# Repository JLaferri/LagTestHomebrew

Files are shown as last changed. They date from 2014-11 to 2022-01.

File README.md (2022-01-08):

Right now this readme will contain the very minimal information required to duplicate my lag tester. If anyone wants to make a more detailed guide I'm open to placing it here, or linking to it.

Here is a demonstation video of the device in use: https://www.youtube.com/watch?v=UTNUIQtreXQ

## Theory and Limitations
Currently this method only works using a Wii with homebrew channel installed. In order for the test to work you need to have a display that emits white light synced up with a sound cue. Both are picked up by the board and the offset is used to calculate the lag. The theory behind it is that the audio will never be delayed whereas the video will be. A CRT is used for calibration.

The Wii limitation could be eliminated if someone designed something else that created these same signals on generic displays. The nice thing about using the Wii is that you know you are providing the same output to the monitor that you would playing a smash game on Wii.

## Board
Click the following link to order some boards or download the gerbers:



Another fab that I recommend if you want to get a few more made is https://www.seeedstudio.com/fusion_pcb.html

## Components
https://docs.google.com/spreadsheets/d/1Dj-m-Ip__IdE_k23mZq7f_099_O0pOspUQSO7Uzj5Qs/edit?usp=sharing

The above were the parts I used at some point... This was actually a long time ago so I'm not even sure how useful those part numbers are going to be but it's the best I have.

### Soldering Guide
This isn't really a guide so much as an aid to tell you where to place what components...
https://github.com/JLaferri/LagTestHomebrew/blob/master/SolderGuide.pdf

### Flashing the Processor
Once you have soldered the board together you will need to flash the processor with the code required to do the testing and run the display. The processor design is based on an Arduino and this can be done using the Arduino IDE. Open the IDE, select the correct programmer, and flash using the programmer. You will need a programmer such as https://www.sparkfun.com/products/9825

The Arduino file can be found here:
https://github.com/JLaferri/LagTestHomebrew/blob/master/Arduino%20Code/lagtester_current.ino

## Homebrew App
The following folder contains the app files to be used on homebrew channel on a hacked Wii
https://github.com/JLaferri/LagTestHomebrew/tree/master/HomebrewApp/compiled/LagTestHomebrew

### Building
For instructions on making changes to the app and building, go here: https://github.com/JLaferri/LagTestHomebrew/tree/master/HomebrewApp

## Additional Materials
Depending on what you intend to test you might need audio converters/extenders. Here are a few that I've used:
* https://www.amazon.com/gp/product/B00004Z5CP
* https://www.amazon.com/Female-Audio-Extension-Cable-CNE63133/dp/B00B973X20

You'll also need to purchase a 9V battery.

## Instructions
This sections explains how to actually use the tester

### Calibration
To add... I think it works kinda like the process in the next section but you gotta hold the button down first? I need to remember how to do this lol. Without calibrating, however, results will be meaningless. A "safe" CRT should be used to calibrate.

### Executing a Test
1. Ensure that the room you are testing in is not flooded with sunlight. The light sensor works by detecting lux and the sun will saturate the voltage output because it produces a lot of it. Too much artificial lighting is also not good but you should be fine as long as there's not a really bright light right behind the monitor you're testing or something.
2. Place a 9V battery in holder. The polarity is marked on the plastic. Do not reverse the polarity as I have not tested what would happen if you do. Worst case scenario, you'd fry the board. More likely though is that nothing would happen.
3. Plug audio cable into the device. Ideally this audio source comes directly from the Wii. In the case of the Sewell adapter use the cable I provided at its output and plug into board. If using component cables you might need to get an RCA connection extender for the audio to reach the device while maintaining mobility. You can also use the audio output of the monitor if it has one but you run the risk that if the monitor adds latency to the audio signal the measurement will be wrong.
4. Turn on the device by flipping the on off switch to on.
5. Boot into the homebrew app.
6. A white bar should be flashing on and off on the monitor, this is the test area. Place the device such that the clear light sensor on the bottom of the board is over the test area. For a CRT, keep a fair distance from the screen (probably at least 5 inches), you don't need to be overly precise about being directly in front of the test area on a CRT as it shoots out a fair amount of light. For an LCD I would recommend placing the sensor about half an inch to one inch away from the screen.
7. Holding the tester in place in front of the test area, press the push button on the top of the board. Wait until either an error code, indicated by the value Err#, or a result in milliseconds appears on the display.
8. Optionally take a few measurements to ensure repeatability.
9. Press A on the Wii Mote to move to the next test area.
10. Repeat steps 6 to 9 for the two other test areas (middle, bottom). Taking an equal amount of measurements for each.
11. Average all results to get the average frame lag of the display. On a CRT this should be close to 8.33 ms.

### Error codes
* Err0 - Audio is not begin detected. Either the amplitude of the audio signal has been reduced (via turning down the volume of a monitor output for example), the homebrew application is not running, or the cable is not plugged in.
* Err1 - Audio cable was disconnected during test?
* Err2 - Audio signal is stuck high for some reason. Not sure what would cause this.
* Err3 - Video signal difference between black and white is not large enough. Is the sensor in front of the test area?

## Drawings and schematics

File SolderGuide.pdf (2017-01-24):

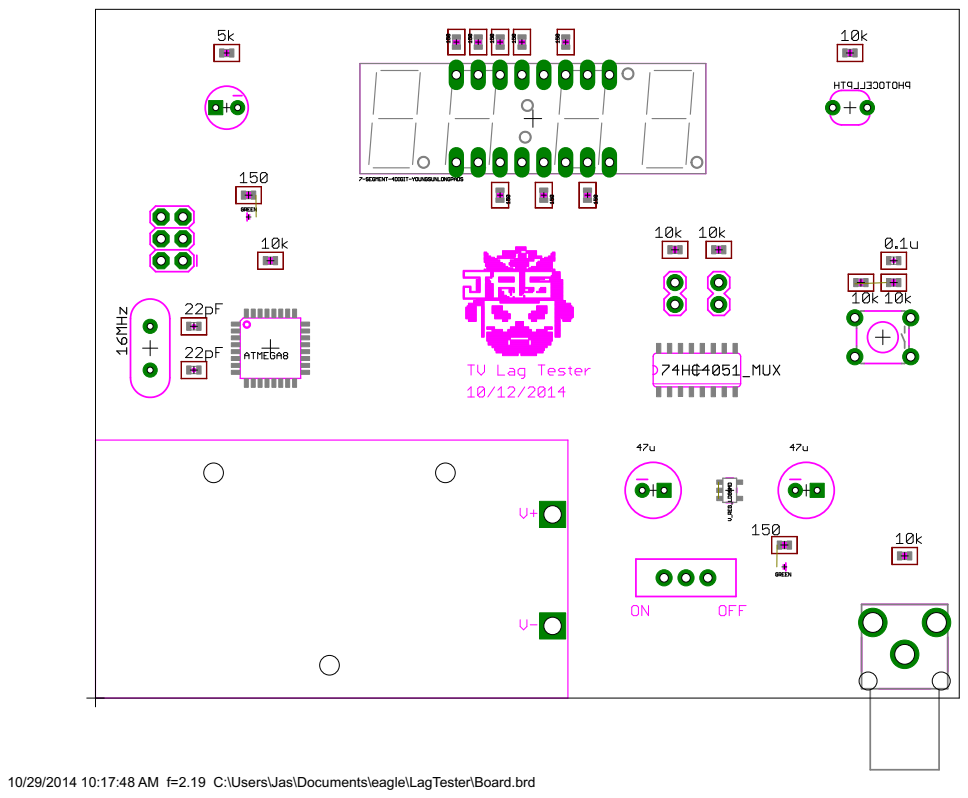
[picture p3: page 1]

10/29/2014 10:17:48 AM f=2.19 C:\Users\Jas\Documents\eagle\LagTester\Board.brd

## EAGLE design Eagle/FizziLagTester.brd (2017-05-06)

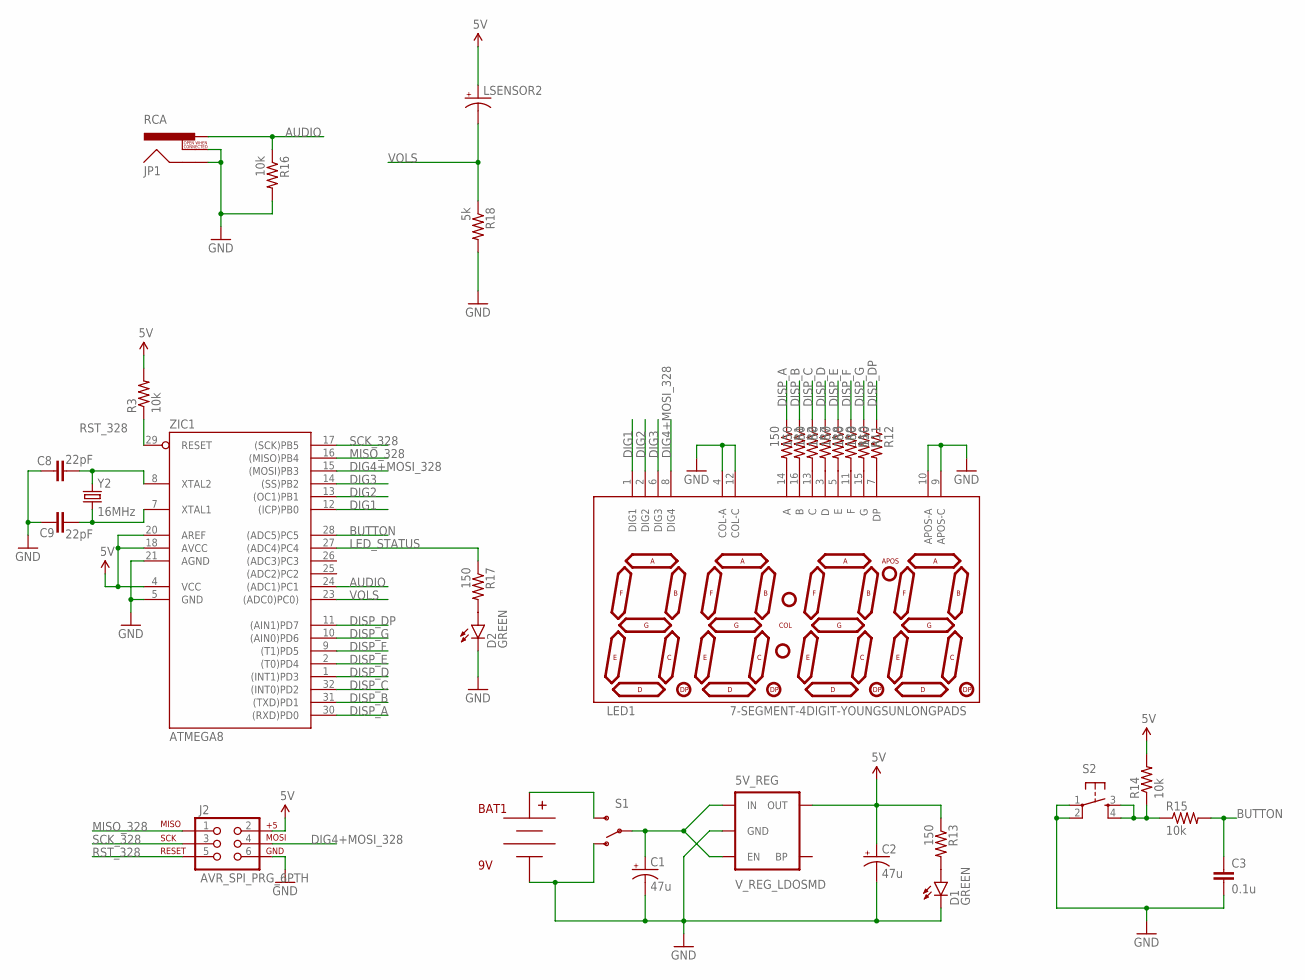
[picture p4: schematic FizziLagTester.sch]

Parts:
5V_REG: V_REG_LDOSMD; SOT23-5
BAT1: 9V; BC9VPC
C1, C2: 47u; CPOL-RADIAL-100UF-25V
C3: 0.1u; 0603-CAP
C8, C9: 22pF; 0603-CAP
D1, D2: GREEN; LED-0603
J2: AVR_SPI_PRG_6PTH; 2X3
JP1: RCA
LED1: 7-SEGMENT-4DIGIT-YOUNGSUNLONGPADS; 7-SEGMENT-4DIGIT-YOUNGSUN-LONGPADS
LSENSOR2: CAP_POLPTH2; CPOL-RADIAL-10UF-25V
R1, R2, R7, R8, R9, R10, R11, R12, R13, R17: 150; 0603-RES
R3, R14, R15, R16: 10k; 0603-RES
R18: 5k; 0603-RES
S1: SWITCH-SPDTPTH; SWITCH-SPDT
S2: TAC_SWITCHPTH; TACTILE-PTH
Y2: 16MHz; HC49US
ZIC1: ATMEGA8; TQFP32-08

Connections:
5V: 5V_REG.5 (OUT), C2.1 (+), J2.2, LSENSOR2.1 (+), R3.2, R13.1, R14.2, ZIC1.4 (VCC), ZIC1.18 (AVCC), ZIC1.20 (AREF)
AUDIO: JP1.PIN, R16.1, ZIC1.24 ((ADC1)PC1)
BUTTON: C3.1, R15.2, ZIC1.28 ((ADC5)PC5)
DIG1: LED1.1 (DIG1), ZIC1.12 ((ICP)PB0)
DIG2: LED1.2 (DIG2), ZIC1.13 ((OC1)PB1)
DIG3: LED1.6 (DIG3), ZIC1.14 ((SS)PB2)
DIG4+MOSI_328: J2.4, LED1.8 (DIG4), ZIC1.15 ((MOSI)PB3)
DISP_A: R1.1, ZIC1.30 ((RXD)PD0)
DISP_B: R2.1, ZIC1.31 ((TXD)PD1)
DISP_C: R7.1, ZIC1.32 ((INT0)PD2)
DISP_D: R8.1, ZIC1.1 ((INT1)PD3)
DISP_DP: R12.1, ZIC1.11 ((AIN1)PD7)
DISP_E: R9.1, ZIC1.2 ((T0)PD4)
DISP_F: R10.1, ZIC1.9 ((T1)PD5)
DISP_G: R11.1, ZIC1.10 ((AIN0)PD6)
GND: 5V_REG.2 (GND), BAT1.V-, C1.2 (-), C2.2 (-), C3.2, C8.2, C9.2, D1.C, D2.C, J2.6, JP1.SHELL, JP1.SWITCH, LED1.4 (COL-A), LED1.9 (APOS-C), LED1.10 (APOS-A), LED1.12 (COL-C), R16.2, R18.2, S1.1 (O), S2.1, S2.2, ZIC1.5 (GND), ZIC1.21 (AGND)
LED_STATUS: R17.1, ZIC1.27 ((ADC4)PC4)
MISO_328: J2.1, ZIC1.16 ((MISO)PB4)
unnamed: LED1.14 (A), R1.2
unnamed: LED1.16 (B), R2.2
unnamed: C8.1, Y2.2, ZIC1.8 (XTAL2)
unnamed: C9.1, Y2.1, ZIC1.7 (XTAL1)
unnamed: LED1.13 (C), R7.2
unnamed: LED1.3 (D), R8.2
unnamed: LED1.5 (E), R9.2
unnamed: LED1.11 (F), R10.2
unnamed: LED1.15 (G), R11.2
unnamed: LED1.7 (DP), R12.2
unnamed: BAT1.V+, S1.3 (S)
unnamed: 5V_REG.1 (IN), 5V_REG.3 (EN), C1.1 (+), S1.2
unnamed: D1.A, R13.2
unnamed: R14.1, R15.1, S2.3, S2.4
unnamed: D2.A, R17.2
RST_328: J2.5, R3.1, ZIC1.29 (RESET)
SCK_328: J2.3, ZIC1.17 ((SCK)PB5)
VOLS: LSENSOR2.2 (-), R18.1, ZIC1.23 ((ADC0)PC0))

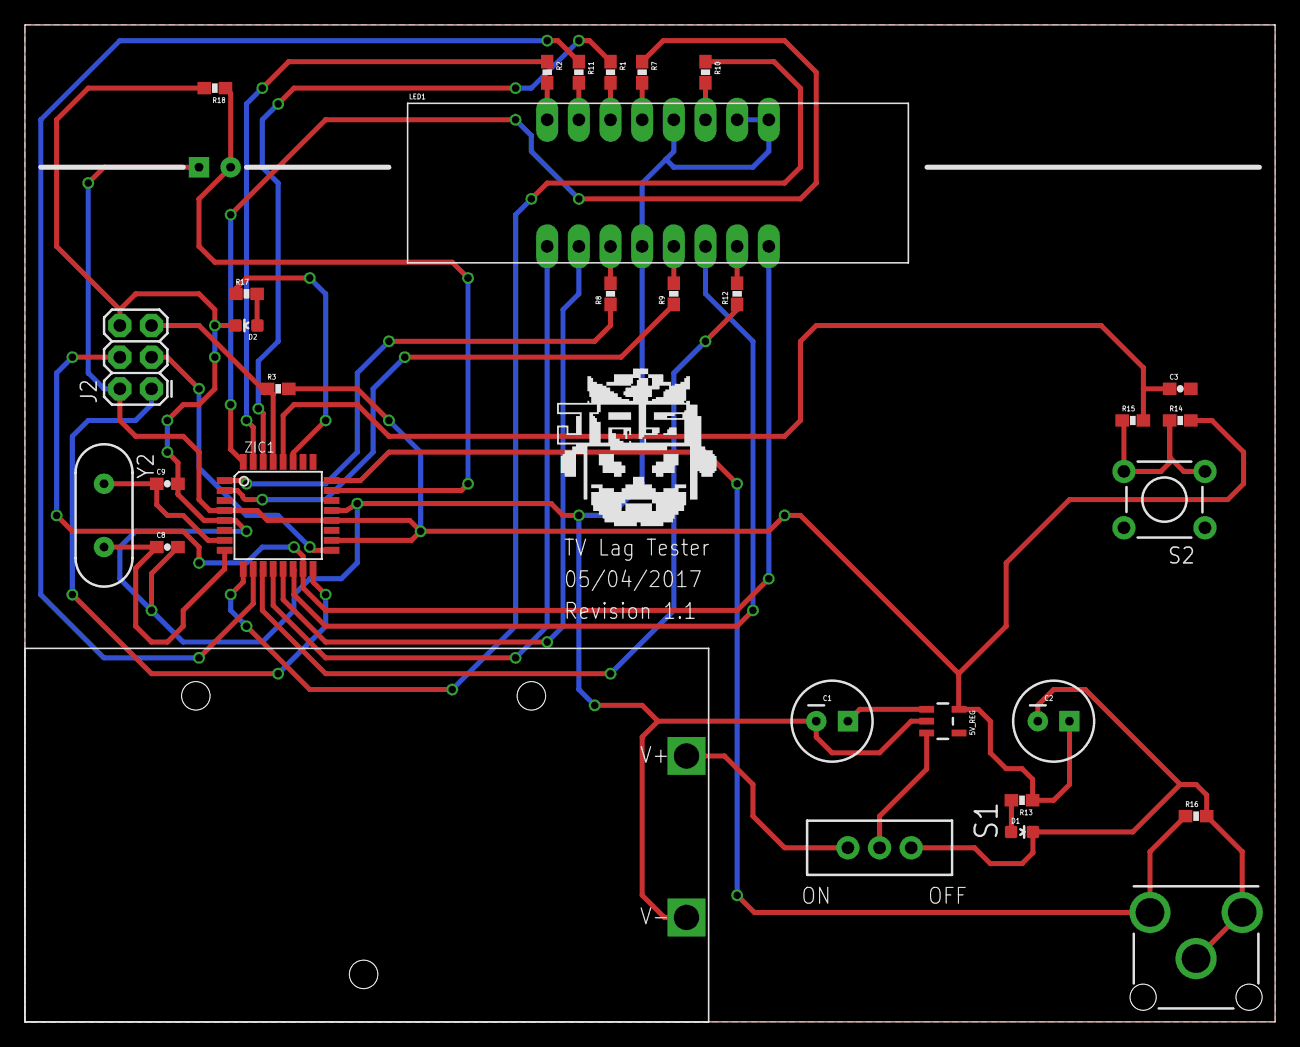
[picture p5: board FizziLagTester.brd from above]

Board: 2 copper layers, 100.3 x 80.0 mm, 32 parts (1 on the bottom side), 36 nets.

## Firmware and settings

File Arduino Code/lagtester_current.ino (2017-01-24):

#include <EEPROM.h>

//Configurable Properties
int ledPin = 18;
int buttonPin = 19;
int lightPin = 0;
int audioPin = 1;

int measurementCountToAverage = 3; //Amount of measurements to average before reporting result

int audioThreshold = 61; //Amount of DAC counts required to detect a positive audio signal
int audioLowThreshold = 5; //DAC count values below this number are considered as no audio signal detected
int lightCountsDifferenceThreshold = 25; //Amount of DAC counts between min and max light values to allow measurement to proceed
float lightRiseRatioRequired = 0.25; //Percent towards maximum light value before the light signal is accepted 
unsigned long measurementSignalOffset_us = 24440; //Average raw frame lag of a CRT. This is basically the amount of desync time between the audio signal and the light signal on the homebrew app
unsigned long calibrationMonitorCenterTime_us = 8333; //The desired measurement reading for the center screen measurement of the calibration monitor (CRT)

unsigned long periodMicros = 1000000; //The period of the audio and light signal in microseconds
int periodCountInitialization = 3; //Amount of periods to wait to get a good concept of the min and max light values

//Sequencing Properties
unsigned long period150Percent = periodMicros + (periodMicros / 2);
unsigned long period200Percent = 2 * periodMicros;
unsigned long period25Percent = periodMicros / 4;
unsigned long periodMicrosLess10Percent = periodMicros - (periodMicros / 10);
unsigned long periodMicrosPlus10Percent = periodMicros + (periodMicros / 10);
unsigned long timeoutMicros = (periodMicros / 2) - (periodMicros / 20);

byte digits[] =
{
  B11111111,
  B11111111,
  B11111111,
  B11111111
};

int currentDigit = 0;

boolean isMeasuring = false;
boolean isCalibration = false;
boolean isButtonPressed = false;
boolean audioDetected = false;

unsigned long measurementStartTime = 0;
unsigned long audioTime = 0;

unsigned long buttonPressTime = 0;

unsigned long buttonTimeForCal_ms = 5000;

int lightMax = 0;
int lightMin = 1023;
int lightThreshold = 0;

int measurementCount = 0;
long measurementAverage = 0;

void setup()
{
  //Set all of PortD pins as outputs
  DDRD = B11111111;
  
  //Set the first 4 bits of PortB as outputs
  DDRB = DDRB | B00001111;
  
  //Initialize Status LED pin
  pinMode(ledPin, OUTPUT);
  digitalWrite(ledPin, LOW);
  
  //Initialize button pin
  pinMode(buttonPin, INPUT);
  
  //Load calibration value
  loadCalValue();
  
  //Initialize digits
  setDigits("0.000");
}

void loadCalValue()
{
  unsigned long value = (EEPROM.read(0) << 24) | EEPROM.read(1) << 16 | EEPROM.read(2) << 8 | EEPROM.read(3);
  
  //If calibration value is not set, set it to the default
  if (value == 0xFFFF)
  {
    setCalValue(measurementSignalOffset_us);
  }
  else
  {
    measurementSignalOffset_us = value; 
  }
}

void setCalValue(unsigned long value)
{
  EEPROM.write(0, byte(value >> 24));
  EEPROM.write(1, byte(value >> 16));
  EEPROM.write(2, byte(value >> 8));
  EEPROM.write(3, byte(value));
  
  measurementSignalOffset_us = value;
}

void turnOnStatusLed()
{
  digitalWrite(ledPin, HIGH);
}

void turnOffStatusLed()
{
  digitalWrite(ledPin, LOW);
}

byte getBitsFromChar(char c)
{
  switch(c)
  {
    case '0':
      return B11000000;
    case '1':
      return B11111001;
    case '2':
      return B10100100;
    case '3':
      return B10110000;
    case '4':
      return B10011001;
    case '5':
      return B10010010;
    case '6':
      return B10000010;
    case '7':
      return B11111000;
    case '8':
      return B10000000;
    case '9':
      return B10010000;
    case 'H':
      return B10001001;
    case 'h':
      return B10001011;
    case 'E':
      return B10000110;
    case 'r':
      return B10101111;
    case 'C':
      return B11000110;
    case 'A':
      return B10001000;
    case 'L':
      return B11000111;
    case '-':
      return B10111111;
    case '.':
      return B01111111;
    default:
      return B11111111;
  }
}

void setDigits(String str)
{
  int charCount = str.length();
  int count = 0, digCount = 0;
  
  while(count < charCount && digCount < 4)
  {
    char currentCharacter = str[count];
    byte bits = getBitsFromChar(currentCharacter);
    
    if (currentCharacter != '.' && (count + 1) < charCount && str[count + 1] == '.')
    {
      digits[digCount] = bits & B01111111;
      count++;
    }
    else
    {
      digits[digCount] = bits;
    }
    
    digCount++;
    count++; 
  }
}

void setDigits(float value)
{
  char buf[12]; // needs to be at least large enough to fit the formatted text
  dtostrf(value, 4, 4, buf);
  
  setDigits(String(buf));
}

void displayAlternatingDigit()
{
  //Enable current digit
  PORTB = (PORTB & B11110000) | (B0001 << currentDigit);
  
  //Turn on bits for current digit value
  PORTD = digits[currentDigit];
  
  currentDigit = (currentDigit + 1) % 4;
}

void displaySingleDigit(char digit, byte locations)
{
  //Enable digits specified by locations byte
  PORTB = (PORTB & B11110000) | (locations & B1111);
  
  //Set digit to passed digit
  PORTD = getBitsFromChar(digit);
}

void initializeMeasurement()
{
  isMeasuring = true;
  measurementStartTime = micros();
  
  audioTime = 0;
  audioDetected = false;
  
  measurementCount = 0;
  measurementAverage = 0;
  
  lightMax = 0;
  lightMin = 1023;

  //Measurement is starting, synchronize procedure by waiting for one entire period while polling the light sensor.
  //This will also keep track of the min and max light values for calculating percent of max brightness (75% default).
  //This is so that CRTs and LCDs have a more fair comparison because LCDs take time to reach full brightness.
  unsigned long timeToAccumulateLight = periodMicros * periodCountInitialization;
  while (getTimeSpanValue(measurementStartTime, micros()) < timeToAccumulateLight)
  {
    int lightCounts = analogRead(lightPin);
  
    if (lightCounts > lightMax) lightMax = lightCounts;
    if (lightCounts < lightMin) lightMin = lightCounts;
  }
  
  lightThreshold = (int)floor(lightMin + lightRiseRatioRequired * (lightMax - lightMin));
  
  //Wait until signal is low
  unsigned long audioTimeoutTime = timeToAccumulateLight + periodMicros;
  while (analogRead(audioPin) > audioLowThreshold)
  {
    //If time since measurement start is greater than 1 second, throw an error.
    if (getTimeSpanValue(measurementStartTime, micros()) > audioTimeoutTime)
    {
      setDigits("Err2");
      isMeasuring = false; //Return to displaying digits
    }
  }
  
  //If min and max light values are not different enough, throw error. This would mean light is saturated or no light is being detected
  if (isMeasuring && lightMax - lightMin < lightCountsDifferenceThreshold)
  {
    setDigits("Err3");
    isMeasuring = false; //Return to displaying digits
  }
}

unsigned long getTimeSpanValue(unsigned long past, unsigned long current)
{
    //Add overflow logic to this function
    return current - past;
}

void loop()
{
  if (!isMeasuring)
  {
    //Until measurement starts display different digits
    displayAlternatingDigit();
    delay(2);
      
    byte buttonResult = digitalRead(buttonPin);
    
    if (buttonResult == LOW && !isButtonPressed)
    {
      //Button press falling edge
      buttonPressTime = millis();
      isButtonPressed = true;
      
      //Turn off cal LED when button is pressed
      turnOffStatusLed();
      isCalibration = false;
    }
    else if (buttonResult == HIGH && isButtonPressed)
    {
       //Button was released, start measurement
       
       //Set display to a single digit
       displaySingleDigit('-', B1111);
       
       initializeMeasurement();
       
       isButtonPressed = false;
    }
    else if (buttonResult == LOW && isButtonPressed && !isCalibration && getTimeSpanValue(buttonPressTime, millis()) > buttonTimeForCal_ms)
    {
      //Button held down for cal time trigger
      isCalibration = true;
      setDigits("CAL ");
      
      //Turn on status LED when a cal measurement is triggered
      turnOnStatusLed();
    }
  }
  else
  {
    //Get time and time since last audio
    unsigned long time = micros();
    unsigned long timeDiff = getTimeSpanValue(audioTime, time);
      
    if (!audioDetected && timeDiff > periodMicrosLess10Percent)
    {
      int audioValue = analogRead(audioPin);
      
      //Until audio is detected, do nothing else
      if (audioValue > audioThreshold)
      {
        //Audio is detected, save time and start monitoring light
        audioDetected = true;
        audioTime = time;
      }
      else if (getTimeSpanValue(measurementStartTime, micros()) > (periodMicros * (periodCountInitialization + 1)) && timeDiff > periodMicrosPlus10Percent)
      {
        //Audio hasn't been detected in at least the period of the signal. This likely means the cable isn't plugged in. Show error
        setDigits("Err0");
        isMeasuring = false; //Return to displaying digits
      }
    }
    else if (audioDetected)
    {
      int lightValue = analogRead(lightPin);
      
      //Audio has been detected. Check for light or reset condition
      unsigned long timeSinceAudio = getTimeSpanValue(audioTime, time);
      
      if (lightValue > lightThreshold)
      {
        measurementAverage = (measurementCount * measurementAverage + timeSinceAudio) / (measurementCount + 1);
        measurementCount++;
        
        //If enough results have been averaged, show result and stop measurement
        if (measurementCount >= measurementCountToAverage)
        {
          //If this was a calibration measurement, write the new calibration value to EEPROM
          if (isCalibration)
          {
            unsigned long newCalValue = long(measurementAverage - calibrationMonitorCenterTime_us);
            setCalValue(newCalValue);
            
            setDigits(newCalValue / 1000.0);
          }
          else
          {
            setDigits((measurementAverage - measurementSignalOffset_us) / 1000.0); 
          }
          
          isMeasuring = false; //Return to displaying digits
        }
        
        audioDetected = false;
      }
      else if (timeSinceAudio > timeoutMicros)
      {
        setDigits("Err1");
        isMeasuring = false; //Return to displaying digits
      }
    }
  }
}

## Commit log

2017-05-05 Adds in-progress eagle file
    [FizziLagTester.brd, FizziLagTester.sch]
2017-05-06 I think revision 1.1 should be functional...
    [FizziLagTester.brd, FizziLagTester.sch]

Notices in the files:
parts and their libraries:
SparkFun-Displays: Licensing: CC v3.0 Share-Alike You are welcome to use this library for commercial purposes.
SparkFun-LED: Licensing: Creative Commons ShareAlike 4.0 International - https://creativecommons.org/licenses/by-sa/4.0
